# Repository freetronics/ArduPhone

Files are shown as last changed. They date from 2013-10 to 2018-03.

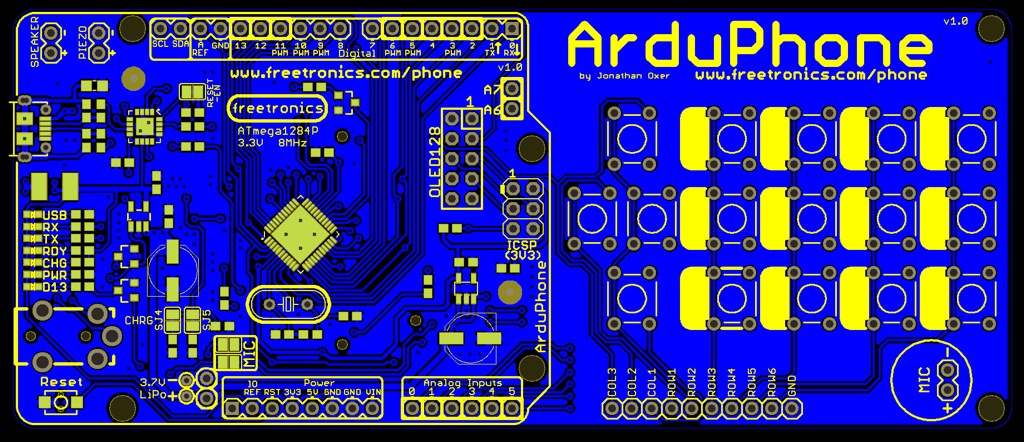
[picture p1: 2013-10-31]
PHONE-top.jpg

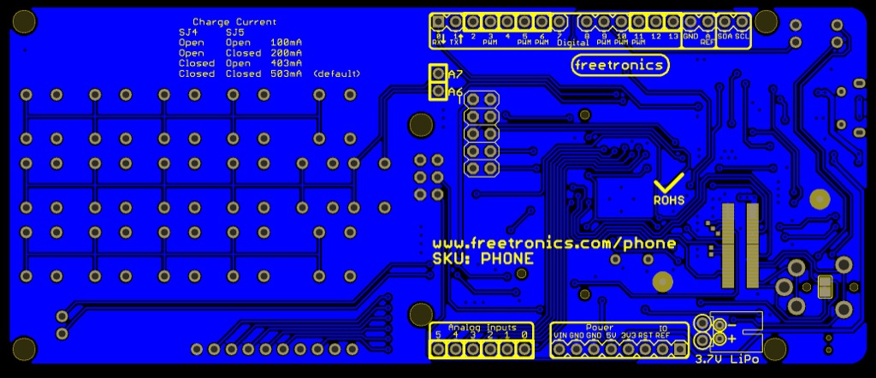
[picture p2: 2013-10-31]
PHONE-bottom.jpg

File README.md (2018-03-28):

Freetronics ArduPhone
=====================
Copyright 2013 Freetronics Pty Ltd www.freetronics.com  

The ArduPhone is an Arduino compatible board with onboard
GSM module, OLED display, matrix keypad, and battery
charger.

Features:

 * Micro-USB connector for charging and programming
 * Overlay guide where you need it (both top and bottom)
 * Mounting holes and power pads

More info at:

  http://www.freetronics.com.au/phone

INSTALLATION
------------
The design is saved as an EAGLE project. EAGLE PCB design software is
available from www.cadsoftusa.com free for non-commercial use. To use
this project download it and place the directory containing these files
into the "eagle" directory on your computer. Then open EAGLE and
navigate to Projects -> eagle -> PHONE.

DISTRIBUTION
------------
The specific terms of distribution of this project are governed by the
license referenced below.

LICENSE
-------
Licensed under the TAPR Open Hardware License (www.tapr.org/OHL).
The "license" folder within this repository also contains a copy of
this license in plain text format.

CREDITS
-------
The ArduPhone was designed by Jonathan Oxer (jon@freetronics.com)
inspired by previous work by David Mellis.

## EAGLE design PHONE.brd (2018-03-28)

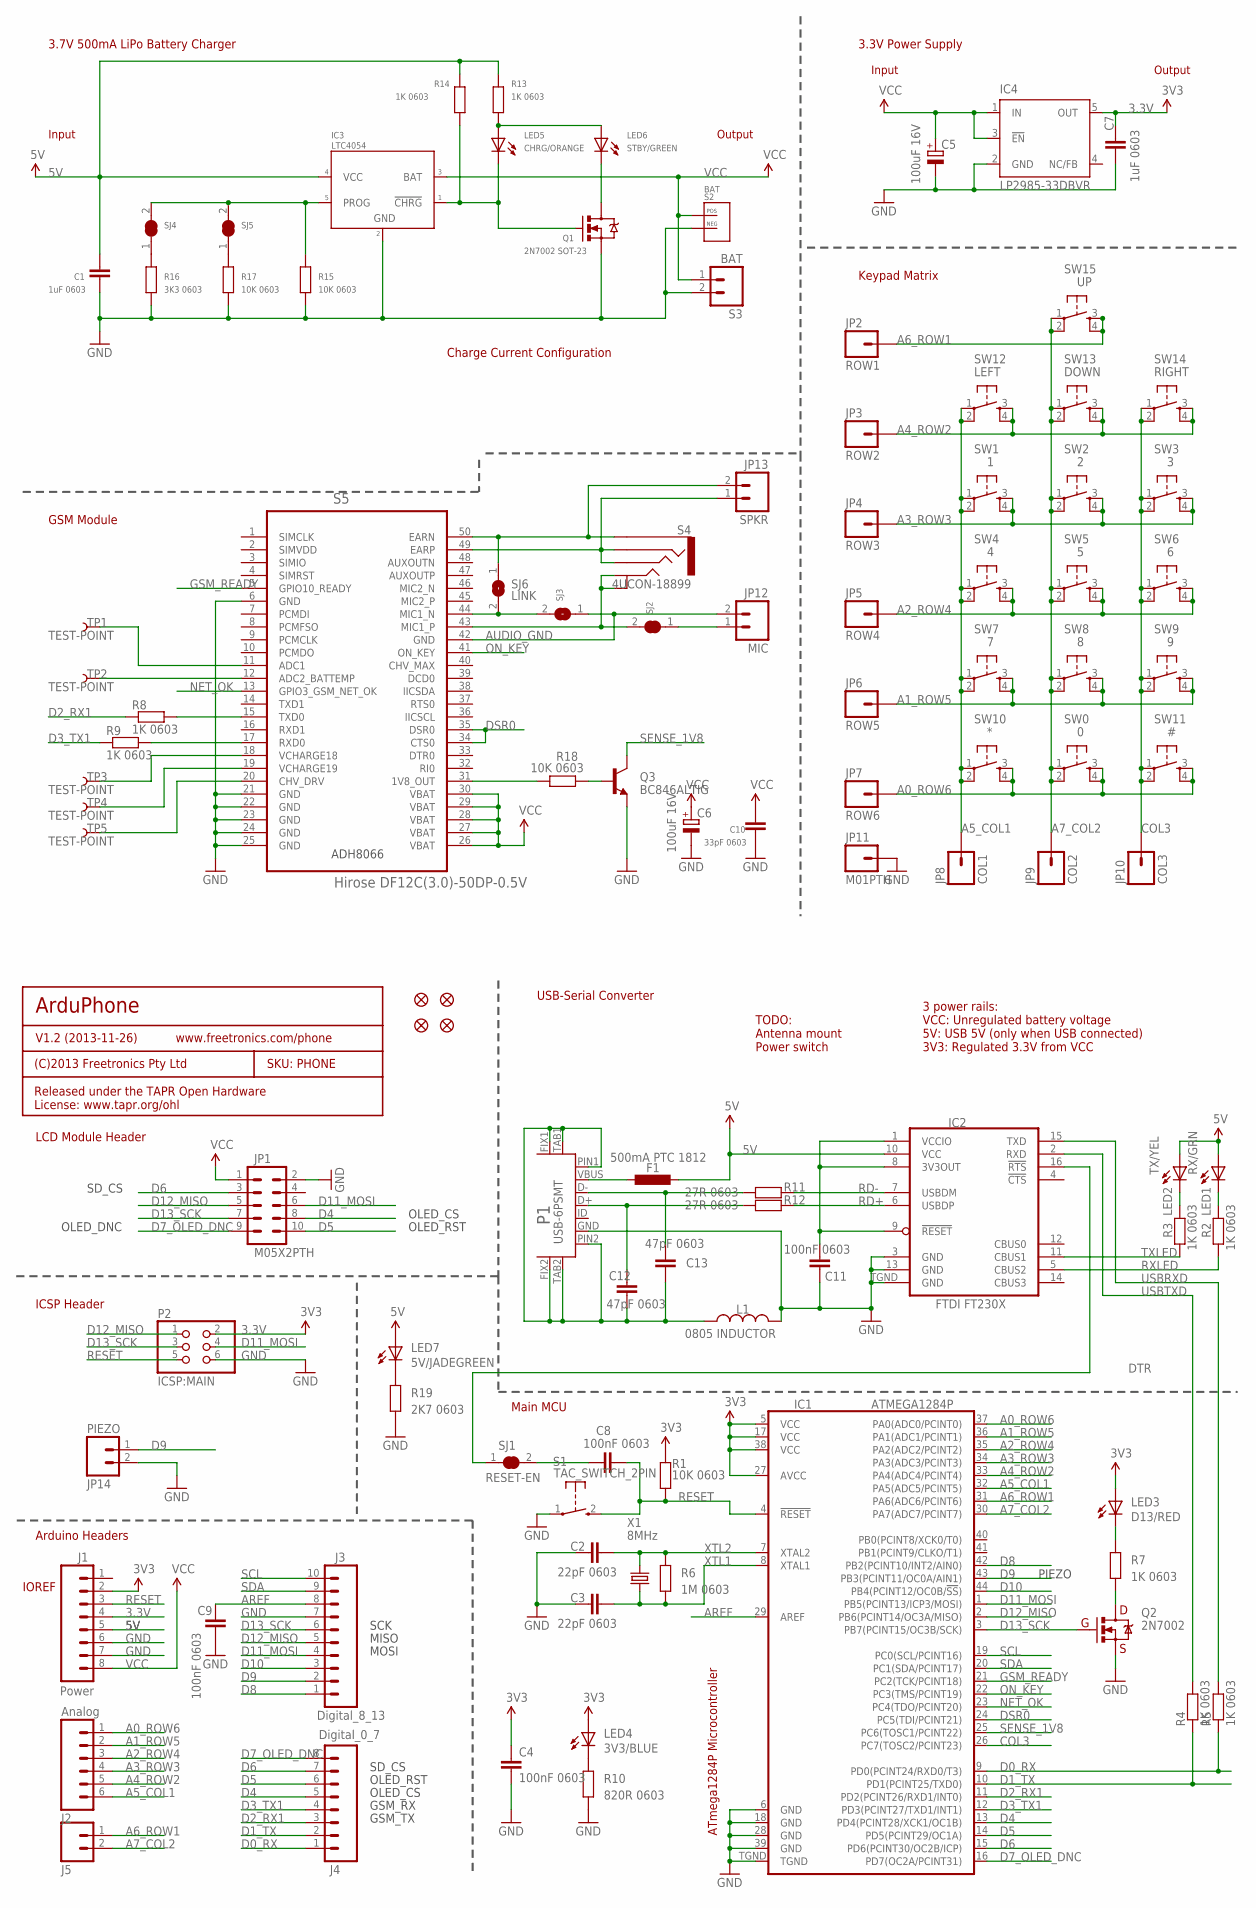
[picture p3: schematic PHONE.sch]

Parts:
C1, C7: 1uF 0603; 0603
C2, C3: 22pF 0603; 0603
C4, C8, C9, C11: 100nF 0603; 0603
C5, C6: 100uF 16V; PANASONIC_D
C10: 33pF 0603; 0603@1
C12, C13: 47pF 0603; C0603
F1: 500mA PTC 1812; L1812
IC1: ATMEGA1284P; QFN-44M1
IC2: FT230X; QFN-16
IC3: LTC4054; SOT23-5
IC4: LP2985-33DBVR; TEXAS_SOT23-DBV
J1: Power; 1X08
J2: Analog; 1X06
J3: Digital_8_13; 1X10
J4: Digital_0_7; 1X08
J5: M02PTH; 1X02
JP1: M05X2PTH; AVR_ICSP
JP2: ROW1; 1X01
JP3: ROW2; 1X01
JP4: ROW3; 1X01
JP5: ROW4; 1X01
JP6: ROW5; 1X01
JP7: ROW6; 1X01
JP8: COL1; 1X01
JP9: COL2; 1X01
JP10: COL3; 1X01
JP11: M01PTH; 1X01
JP12: MIC; 1X02
JP13: SPKR; 1X02
JP14: PIEZO; 1X02
L1: 0805 INDUCTOR; 0805-LARGE
LED1: RX/GRN; LED-0603
LED2: TX/YEL; LED-0603
LED3: D13/RED; LED-0603
LED4: 3V3/BLUE; LED-0603
LED5: CHRG/ORANGE; LED-0603
LED6: STBY/GREEN; LED-0603
LED7: 5V/JADEGREEN; LED-0603
P1: USB-6PSMT; USB-MICROB-MB05PMXX
P2: ICSP:MAIN; 2X03
Q1: 2N7002 SOT-23; SOT23-3
Q2: 2N7002; SOT23-3
Q3: BC846ALTIG; SOT23-3
R1, R15, R17, R18: 10K 0603; 0603
R2, R3, R4, R5, R7, R8, R9, R13, R14: 1K 0603; 0603
R6: 1M 0603; 0603
R10: 820R 0603; 0603
R11, R12: 27R 0603; 0603
R16: 3K3 0603; 0603
R19: 2K7 0603; 0603
S1: TAC_SWITCH_2PIN; TACTILE_SWITCH_SMD_2PIN_TINY
S2: BAT; JST-2MM-TH-RA
S3: BAT; 1X02
S4: 4UCON-18899
S5: Hirose DF12C(3.0)-50DP-0.5V; ADH8066
SJ1: RESET-EN; SJC
SJ2, SJ4, SJ5: SJCN; SJC
SJ3: SJ
SJ6: LINK; SJ
SW0: 0; TACTILE-PTH
SW1: 1; TACTILE-PTH
SW2: 2; TACTILE-PTH
SW3: 3; TACTILE-PTH
SW4: 4; TACTILE-PTH
SW5: 5; TACTILE-PTH
SW6: 6; TACTILE-PTH
SW7: 7; TACTILE-PTH
SW8: 8; TACTILE-PTH
SW9: 9; TACTILE-PTH
SW10: *; TACTILE-PTH
SW11: #; TACTILE-PTH
SW12: LEFT; TACTILE-PTH
SW13: DOWN; TACTILE-PTH
SW14: RIGHT; TACTILE-PTH
SW15: UP; TACTILE-PTH
TP1, TP2, TP3, TP4, TP5: TEST-POINT; PAD.02X.02
U$5, U$6, U$7, U$14: FIDUCIAL1X2.5; FIDUCIAL-1X2.5
X1: 8MHz; HC49U-V

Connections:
3.3V: C4.1, C7.2, IC1.5 (VCC), IC1.17 (VCC), IC1.27 (AVCC), IC1.38 (VCC), IC4.5 (OUT), J1.2, J1.4, LED3.A, LED4.A, P2.2, R1.2
5V: C1.2, F1.2, IC2.10 (VCC), IC3.4 (VCC), J1.5, LED1.A, LED2.A, LED7.A, R13.1, R14.1
A0_ROW6: IC1.37 (PA0(ADC0/PCINT0)), J2.1, JP7.1, SW0.3, SW0.4, SW10.3, SW10.4, SW11.3, SW11.4
A1_ROW5: IC1.36 (PA1(ADC1/PCINT1)), J2.2, JP6.1, SW7.3, SW7.4, SW8.3, SW8.4, SW9.3, SW9.4
A2_ROW4: IC1.35 (PA2(ADC2/PCINT2)), J2.3, JP5.1, SW4.3, SW4.4, SW5.3, SW5.4, SW6.3, SW6.4
A3_ROW3: IC1.34 (PA3(ADC3/PCINT3)), J2.4, JP4.1, SW1.3, SW1.4, SW2.3, SW2.4, SW3.3, SW3.4
A4_ROW2: IC1.33 (PA4(ADC4/PCINT4)), J2.5, JP3.1, SW12.3, SW12.4, SW13.3, SW13.4, SW14.3, SW14.4
A5_COL1: IC1.32 (PA5(ADC5/PCINT5)), J2.6, JP8.1, SW1.1, SW1.2, SW4.1, SW4.2, SW7.1, SW7.2, SW10.1, SW10.2, SW12.1, SW12.2
A6_ROW1: IC1.31 (PA6(ADC6/PCINT6)), J5.1, JP2.1, SW15.3, SW15.4
A7_COL2: IC1.30 (PA7(ADC7/PCINT7)), J5.2, JP9.1, SW0.1, SW0.2, SW2.1, SW2.2, SW5.1, SW5.2, SW8.1, SW8.2, SW13.1, SW13.2, SW15.1, SW15.2
AREF: C9.1, IC1.29 (AREF), J3.8
AUDIO_GND: JP12.2, S5.42 (GND), SJ3.1
COL3: IC1.26 (PC7(TOSC2/PCINT23)), JP10.1, SW3.1, SW3.2, SW6.1, SW6.2, SW9.1, SW9.2, SW11.1, SW11.2, SW14.1, SW14.2
D0_RX: IC1.9 (PD0(PCINT24/RXD0/T3)), J4.1, R5.1
D1_TX: IC1.10 (PD1(PCINT25/TXD0)), J4.2, R4.1
D2_RX1: IC1.11 (PD2(PCINT26/RXD1/INT0)), J4.3, R8.1
D3_TX1: IC1.12 (PD3(PCINT27/TXD1/INT1)), J4.4, R9.1
D4: IC1.13 (PD4(PCINT28/XCK1/OC1B)), J4.5, JP1.8
D5: IC1.14 (PD5(PCINT29/OC1A)), J4.6, JP1.10
D6: IC1.15 (PD6(PCINT30/OC2B/ICP)), J4.7, JP1.3
D7_OLED_DNC: IC1.16 (PD7(OC2A/PCINT31)), J4.8, JP1.9
D8: IC1.42 (PB2(PCINT10/INT2/AIN0)), J3.1
D9: IC1.43 (PB3(PCINT11/OC0A/AIN1)), J3.2, JP14.1
D10: IC1.44 (PB4(PCINT12/OC0B/!SS!)), J3.3
D11_MOSI: IC1.1 (PB5(PCINT13/ICP3/MOSI)), J3.4, JP1.6, P2.4
D12_MISO: IC1.2 (PB6(PCINT14/OC3A/MISO)), J3.5, JP1.5, P2.1
D13_SCK: IC1.3 (PB7(PCINT15/OC3B/SCK)), J3.6, JP1.7, P2.3, Q2.1 (G)
DSR0: IC1.24 (PC5(TDI/PCINT21)), S5.34 (CTS0), S5.35 (DSR0)
DTR: IC2.16 (!RTS), SJ1.1
GND: C1.1, C2.1, C3.1, C4.2, C5.-, C6.-, C7.1, C9.2, C10.1, C11.2, IC1.6 (GND), IC1.18 (GND), IC1.28 (GND), IC1.39 (GND), IC1.TGND, IC2.3 (GND), IC2.13 (GND), IC2.TGND (GND), IC3.2 (GND), IC4.2 (GND), J1.6, J1.7, J3.7, JP1.2, JP11.1, JP14.2, L1.2, P1.GND, P2.6, Q1.2 (S), Q2.2 (S), Q3.2 (E), R10.1, R15.2, R16.2, R17.2, R19.1, S1.1, S2.NEG, S3.2, S5.6 (GND), S5.21 (GND), S5.22 (GND), S5.23 (GND), S5.24 (GND), S5.25 (GND)
GSM_READY: IC1.21 (PC2(TCK/PCINT18)), S5.5 (GPIO10_READY)
unnamed: C8.1, SJ1.2
unnamed: C11.1, IC2.1 (VCCIO), IC2.8 (3V3OUT), IC2.9 (!RESET)
unnamed: C12.2, C13.2, L1.1, P1.FIX1, P1.FIX2, P1.PIN1, P1.PIN2, P1.TAB1, P1.TAB2
unnamed: LED3.C, R7.2
unnamed: LED6.C, Q1.3 (D)
unnamed: Q2.3 (D), R7.1
unnamed: LED7.C, R19.2
unnamed: LED5.A, LED6.A, R13.2
unnamed: S4.2A, S4.2B, S5.43 (MIC1_P), SJ2.2
unnamed: IC3.1 (!CHRG), LED5.C, Q1.1 (G), R14.2
unnamed: LED1.C, R2.2
unnamed: IC3.5 (PROG), R15.1, SJ4.2, SJ5.2
unnamed: LED2.C, R3.2
unnamed: LED4.C, R10.2
unnamed: Q3.1 (B), R18.1
unnamed: C12.1, P1.D+, R12.2
unnamed: C13.1, P1.D-, R11.2
unnamed: S5.44 (MIC1_N), SJ3.2, SJ6.2
unnamed: JP13.2, S4.1, S5.50 (EARN), SJ6.1
unnamed: JP13.1, S4.3, S4.4, S5.49 (EARP)
unnamed: R8.2, S5.15 (TXD0)
unnamed: R9.2, S5.17 (RXD0)
unnamed: S5.18 (VCHARGE18), TP3.P$1
unnamed: S5.19 (VCHARGE19), TP4.P$1
unnamed: S5.20 (CHV_DRV), TP5.P$1
unnamed: R18.2, S5.31 (1V8_OUT)
unnamed: JP12.1, SJ2.1
unnamed: S5.11 (ADC1), TP1.P$1
unnamed: S5.12 (ADC2_BATTEMP), TP2.P$1
unnamed: R16.1, SJ4.1
unnamed: R17.1, SJ5.1
unnamed: F1.1, P1.VBUS
NET_OK: IC1.23 (PC4(TDO/PCINT20)), S5.13 (GPIO3_GSM_NET_OK)
ON_KEY: IC1.22 (PC3(TMS/PCINT19)), S5.41 (ON_KEY)
RD+: IC2.6 (USBDP), R12.1
RD-: IC2.7 (USBDM), R11.1
RESET: C8.2, IC1.4 (!RESET), J1.3, P2.5, R1.1, S1.2 (S)
RXLED: IC2.5 (CBUS2), R2.1
SCL: IC1.19 (PC0(SCL/PCINT16)), J3.10
SDA: IC1.20 (PC1(SDA/PCINT17)), J3.9
SENSE_1V8: IC1.25 (PC6(TOSC1/PCINT22)), Q3.3 (C)
TXLED: IC2.11 (CBUS1), R3.1
USBRXD: IC2.15 (TXD), R5.2
USBTXD: IC2.2 (RXD), R4.2
VCC: C5.+, C6.+, C10.2, IC3.3 (BAT), IC4.1 (IN), IC4.3 (!EN), J1.8, JP1.1, S2.POS, S3.1, S5.26 (VBAT), S5.27 (VBAT), S5.28 (VBAT), S5.29 (VBAT), S5.30 (VBAT)
XTL1: C3.2, IC1.8 (XTAL1), R6.1, X1.1
XTL2: C2.2, IC1.7 (XTAL2), R6.2, X1.2

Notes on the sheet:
ArduPhone
V1.2 (2013-11-26)
SKU: PHONE
(C)2013 Freetronics Pty Ltd
Released under the TAPR Open Hardware License: www.tapr.org/ohl
www.freetronics.com/phone
IOREF
ATmega1284P Microcontroller
3 power rails: VCC: Unregulated battery voltage 5V: USB 5V (only when USB connected) 3V3: Regulated 3.3V from VCC
OLED_DNC
SD_CS
OLED_CS
OLED_RST
TODO: Antenna mount Power switch
Output
Input
3.7V 500mA LiPo Battery Charger
3.3V Power Supply
Keypad Matrix
GSM Module
LCD Module Header
USB-Serial Converter
Main MCU
Arduino Headers
ICSP Header
SCK
MISO
MOSI
GSM_RX
GSM_TX
Charge Current Configuration
ADH8066
PIEZO

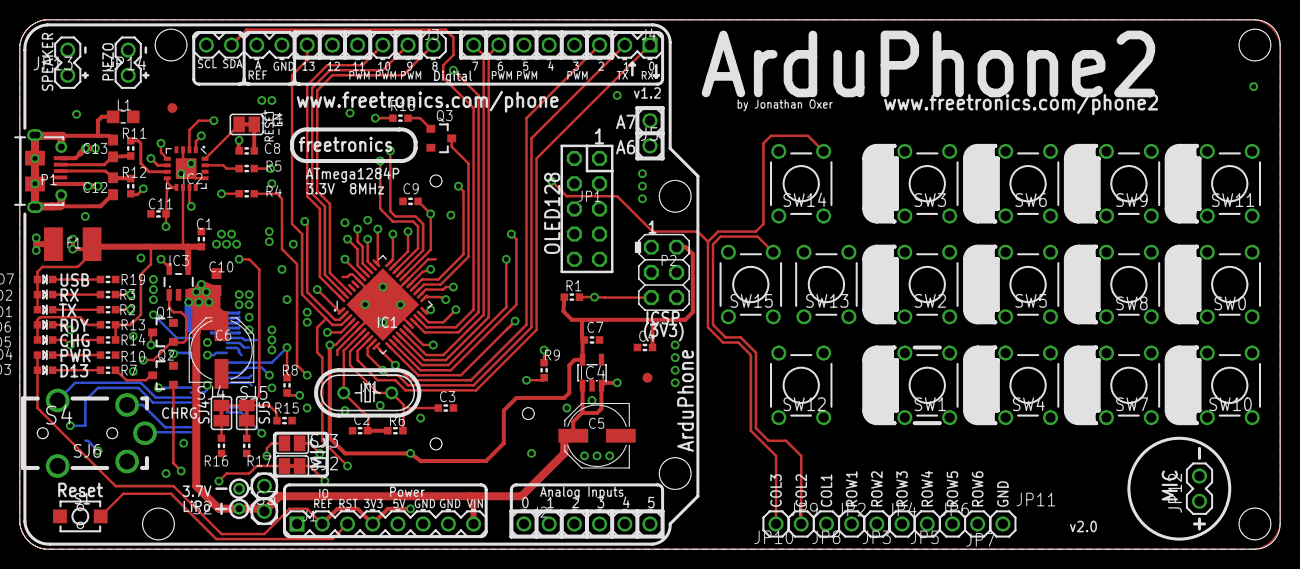
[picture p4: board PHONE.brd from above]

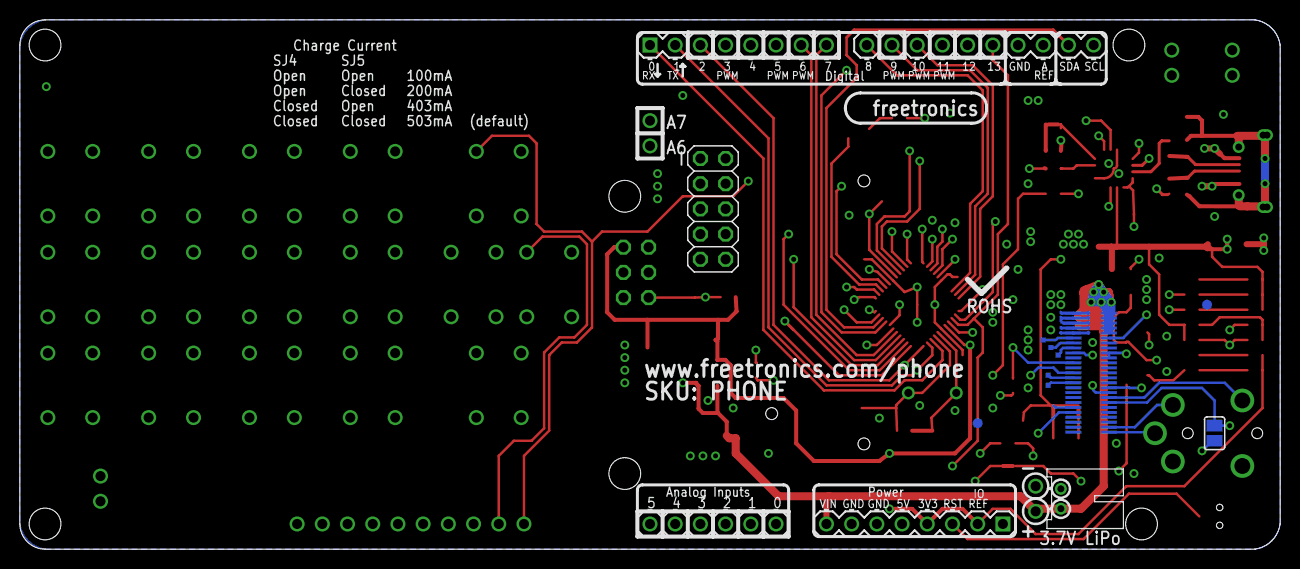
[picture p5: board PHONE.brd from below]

Board: 4 copper layers, 127.0 x 53.3 mm, 106 parts (11 on the bottom side), 78 nets.

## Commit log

2013-10-28 Initial project import
    [PHONE.brd, PHONE.sch]
2013-10-31 v1.0 release
    [PHONE.brd, PHONE.sch]
2013-11-26 v1.1 release: separated AUDIO_GND from system GND
    [PHONE.brd, PHONE.sch]
2013-11-26 Switched to 4 layers and rerouted for v1.2 release
    [PHONE.brd, PHONE.sch]
2014-03-17 Reconciled schematic and layout using common parts
    [PHONE.brd, PHONE.sch]
2018-03-28 Updated designators
    [PHONE.brd]

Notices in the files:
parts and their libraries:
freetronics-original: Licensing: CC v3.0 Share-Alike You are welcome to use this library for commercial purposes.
